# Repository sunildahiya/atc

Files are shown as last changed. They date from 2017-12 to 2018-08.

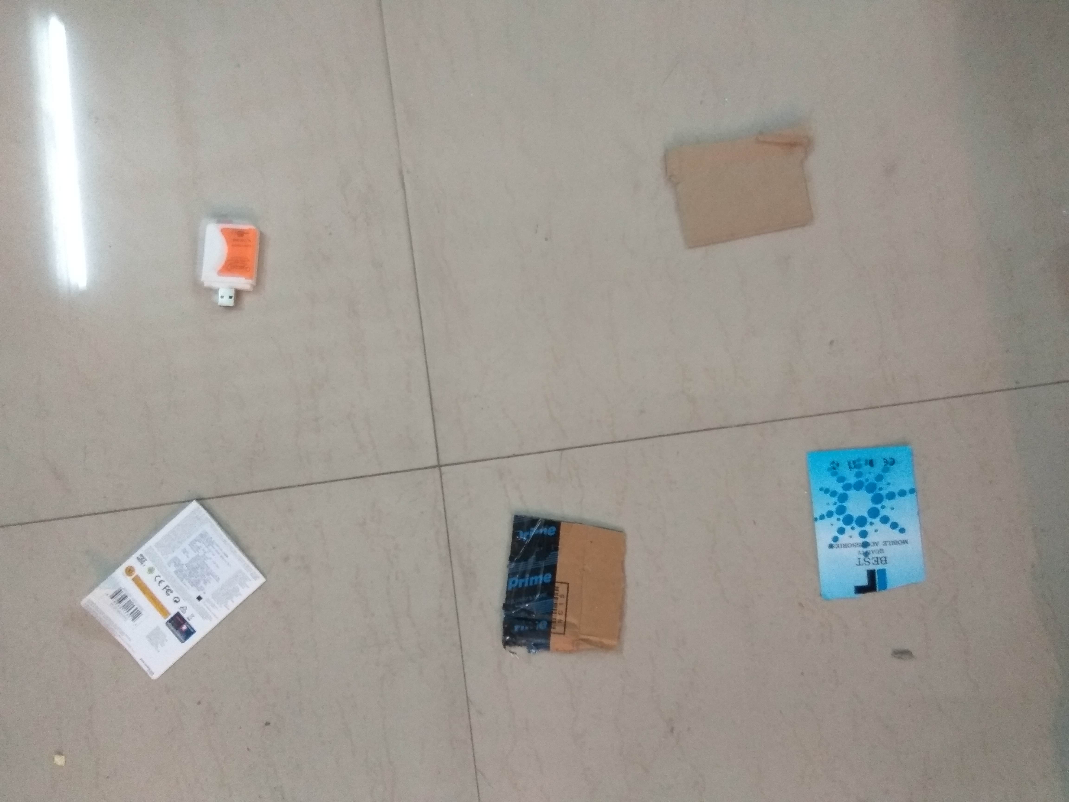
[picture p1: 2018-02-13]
ip/Resources/stain1.jpg

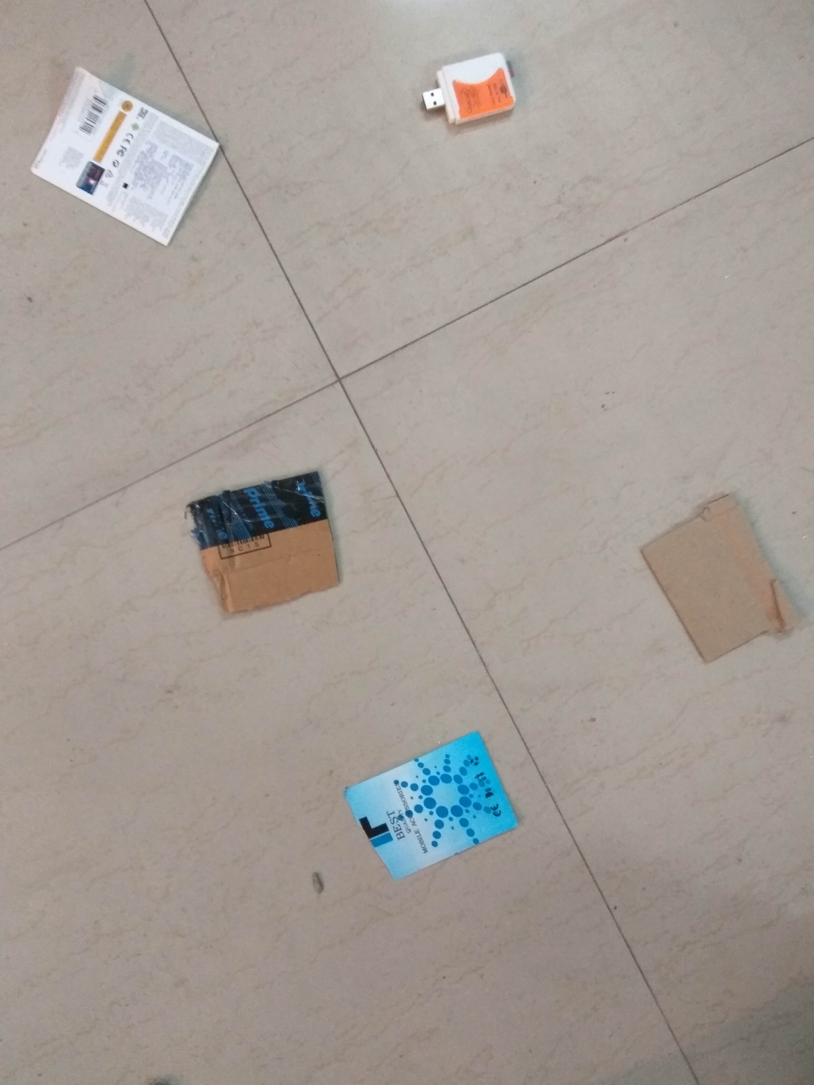
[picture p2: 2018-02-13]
ip/Resources/stain2.jpg

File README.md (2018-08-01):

### Automatic Toilet Cleaner
This repository contains Solidwork design, Navigation Code and IP code for InterIIT Automatic Toilet Cleaner Competition.

#### Minimal HSV Channels for detecting different Color

 1. White    -   Saturation from 0 to someValue
 2. Green    -   Using 1, hue 0 to someValue
 3. Blue     -   saturation from somevalue to 255
 4. Red      -   Using 3, hue from somevalue to 255

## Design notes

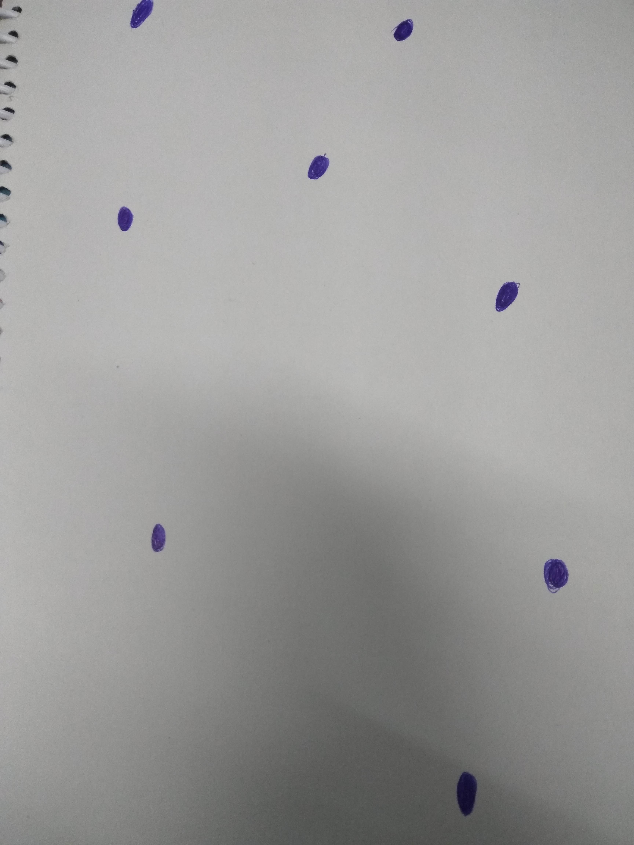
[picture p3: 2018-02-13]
ip/Resources/stains.jpg

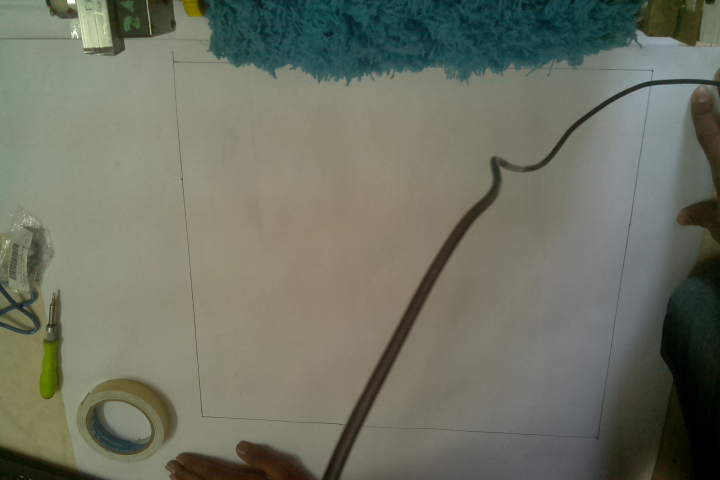
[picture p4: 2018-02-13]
ip/Resources/C.png

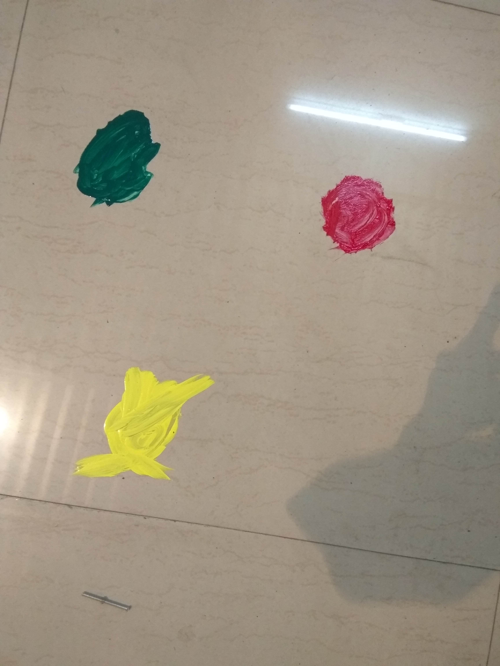
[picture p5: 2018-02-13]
ip/Resources/stain3.jpg

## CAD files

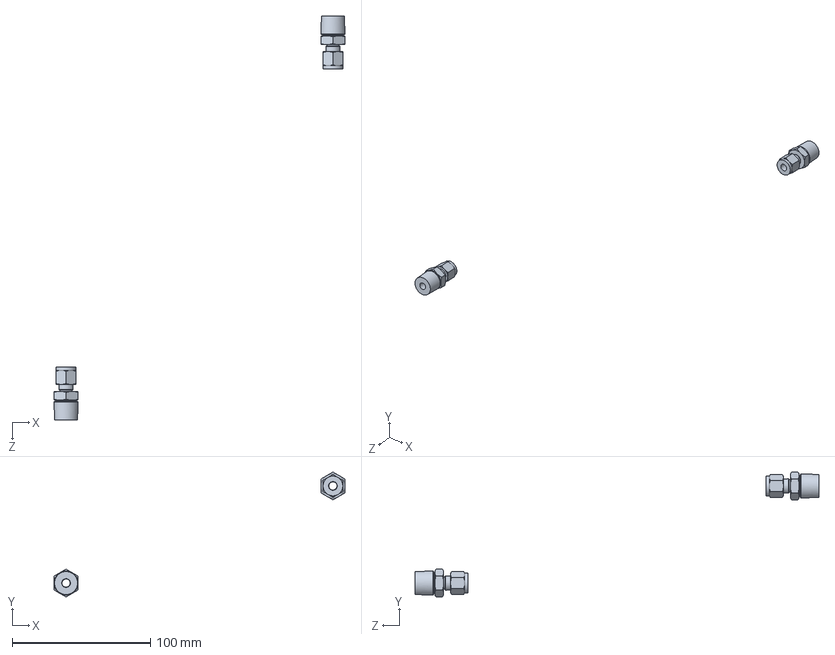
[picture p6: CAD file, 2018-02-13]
Solidworks_Design/Tube_8-Final_bot.sldasm
210.8 x 90.5 x 292.3 mm
straight fitting x 2

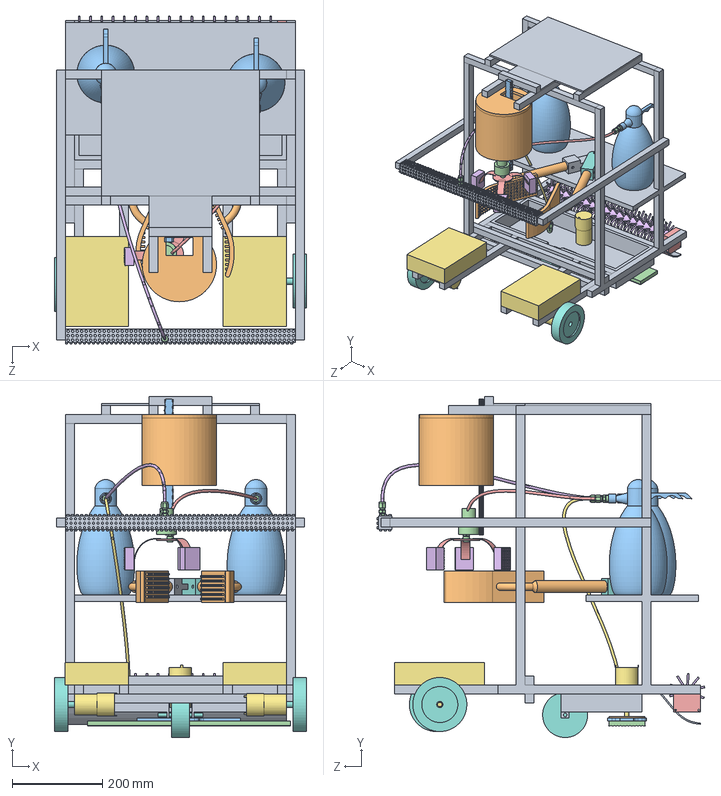
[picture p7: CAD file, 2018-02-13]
Solidworks_Design/Final_bot.SLDASM
560.0 x 756.7 x 727.2 mm
Chasis
cylindrcal shell
rack
motor_bowl
foam brush bowl x 3
motor x 3
wheel x 2
lower sheet trash
rotating circle
scotch piston
cleaning pad
roller motor
rolling brush
weight x 2
side clean brush x 2
wATER BOOTTLE x 2
straight fitting x 6
Tube-250X010^Tube_10-Final_bot
Tube-250X010^Tube_11-Final_bot
Tube-250X010^Tube_12-Final_bot
OMNI

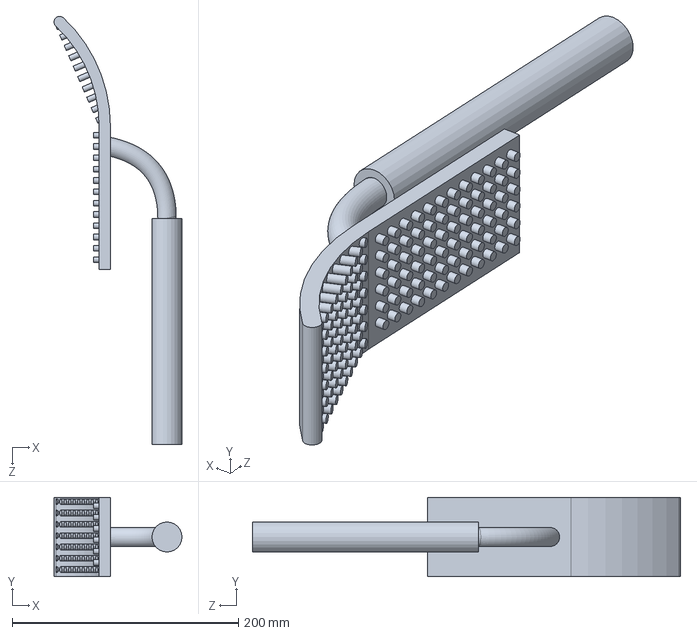
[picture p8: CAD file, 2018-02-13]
Solidworks_Design/side clean brush.SLDPRT
113.1 x 70.0 x 378.4 mm

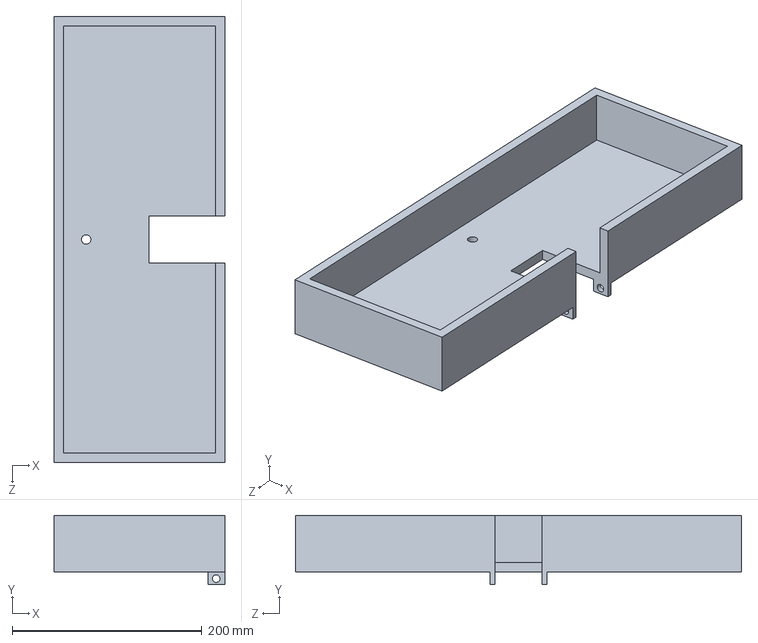
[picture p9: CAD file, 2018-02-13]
Solidworks_Design/lower sheet trash.SLDPRT
180.0 x 73.2 x 470.0 mm

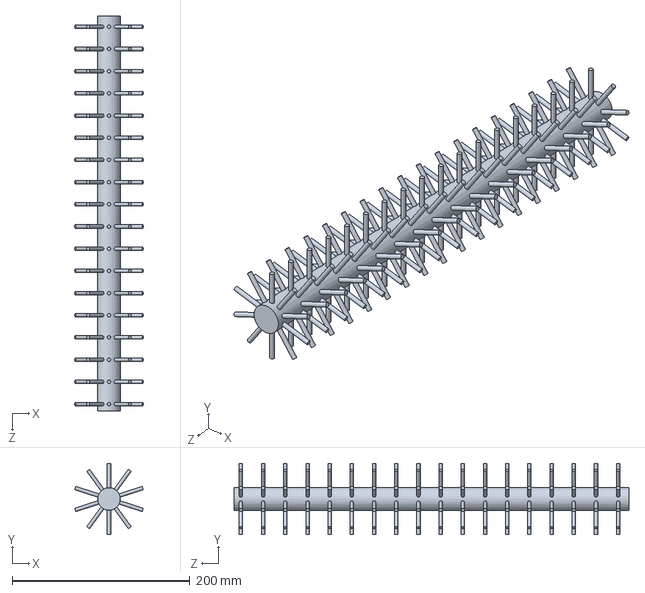
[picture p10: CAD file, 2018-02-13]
Solidworks_Design/rolling brush.SLDPRT
77.3 x 80.0 x 445.0 mm

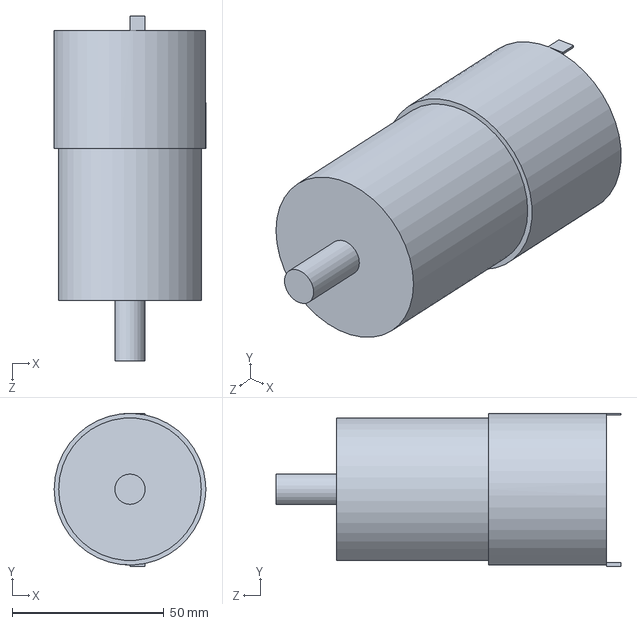
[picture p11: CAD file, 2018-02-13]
Solidworks_Design/motor.SLDPRT
50.0 x 50.5 x 113.7 mm

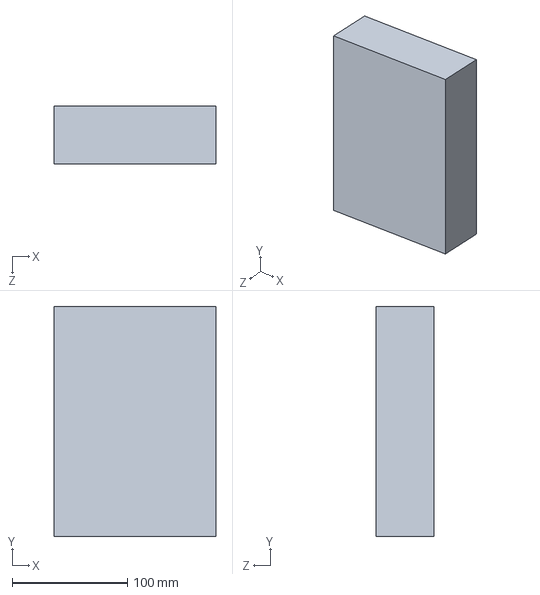
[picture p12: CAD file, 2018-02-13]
Solidworks_Design/weight.SLDPRT
140.8 x 200.0 x 50.0 mm

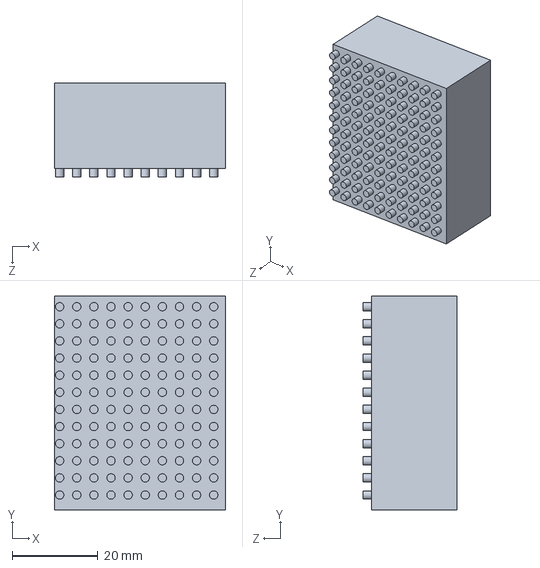
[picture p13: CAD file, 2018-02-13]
Solidworks_Design/foam brush bowl.SLDPRT
40.0 x 50.0 x 22.0 mm

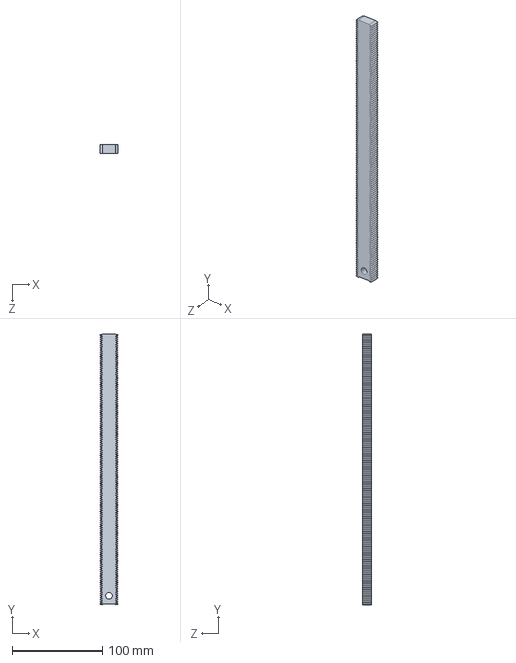
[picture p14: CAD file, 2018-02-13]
Solidworks_Design/rack.SLDPRT
20.0 x 301.1 x 10.0 mm

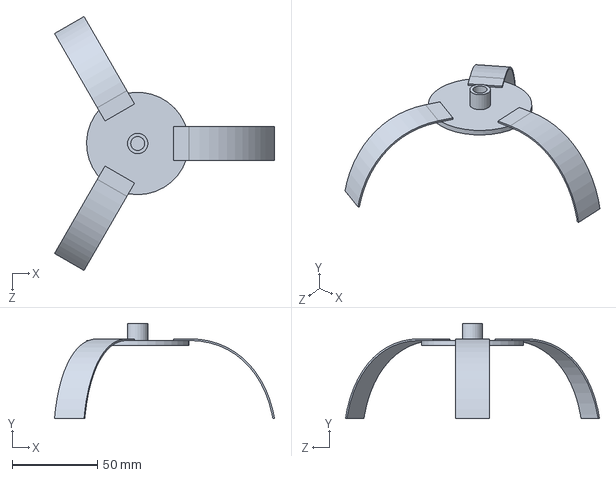
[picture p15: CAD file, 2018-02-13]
Solidworks_Design/Part4.SLDPRT
129.0 x 55.8 x 148.9 mm

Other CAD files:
Solidworks_Design/Tube_7-Final_bot.sldasm
Solidworks_Design/Tube_10-Final_bot.sldasm
Solidworks_Design/RouteAssy_1-Final_bot.sldasm
Solidworks_Design/Tube_11-Final_bot.sldasm
Solidworks_Design/Tube_6-Final_bot.sldasm
Solidworks_Design/Tube_9-Final_bot.sldasm
Solidworks_Design/Tube_12-Final_bot.sldasm
Solidworks_Design/Tube_2-Final_bot.sldasm
Solidworks_Design/Chasis.SLDPRT
Solidworks_Design/OMNI.SLDPRT
Solidworks_Design/cylindrcal shell.SLDPRT
Solidworks_Design/motor_bowl.SLDPRT
Solidworks_Design/roller motor.SLDPRT
Solidworks_Design/wheel.SLDPRT

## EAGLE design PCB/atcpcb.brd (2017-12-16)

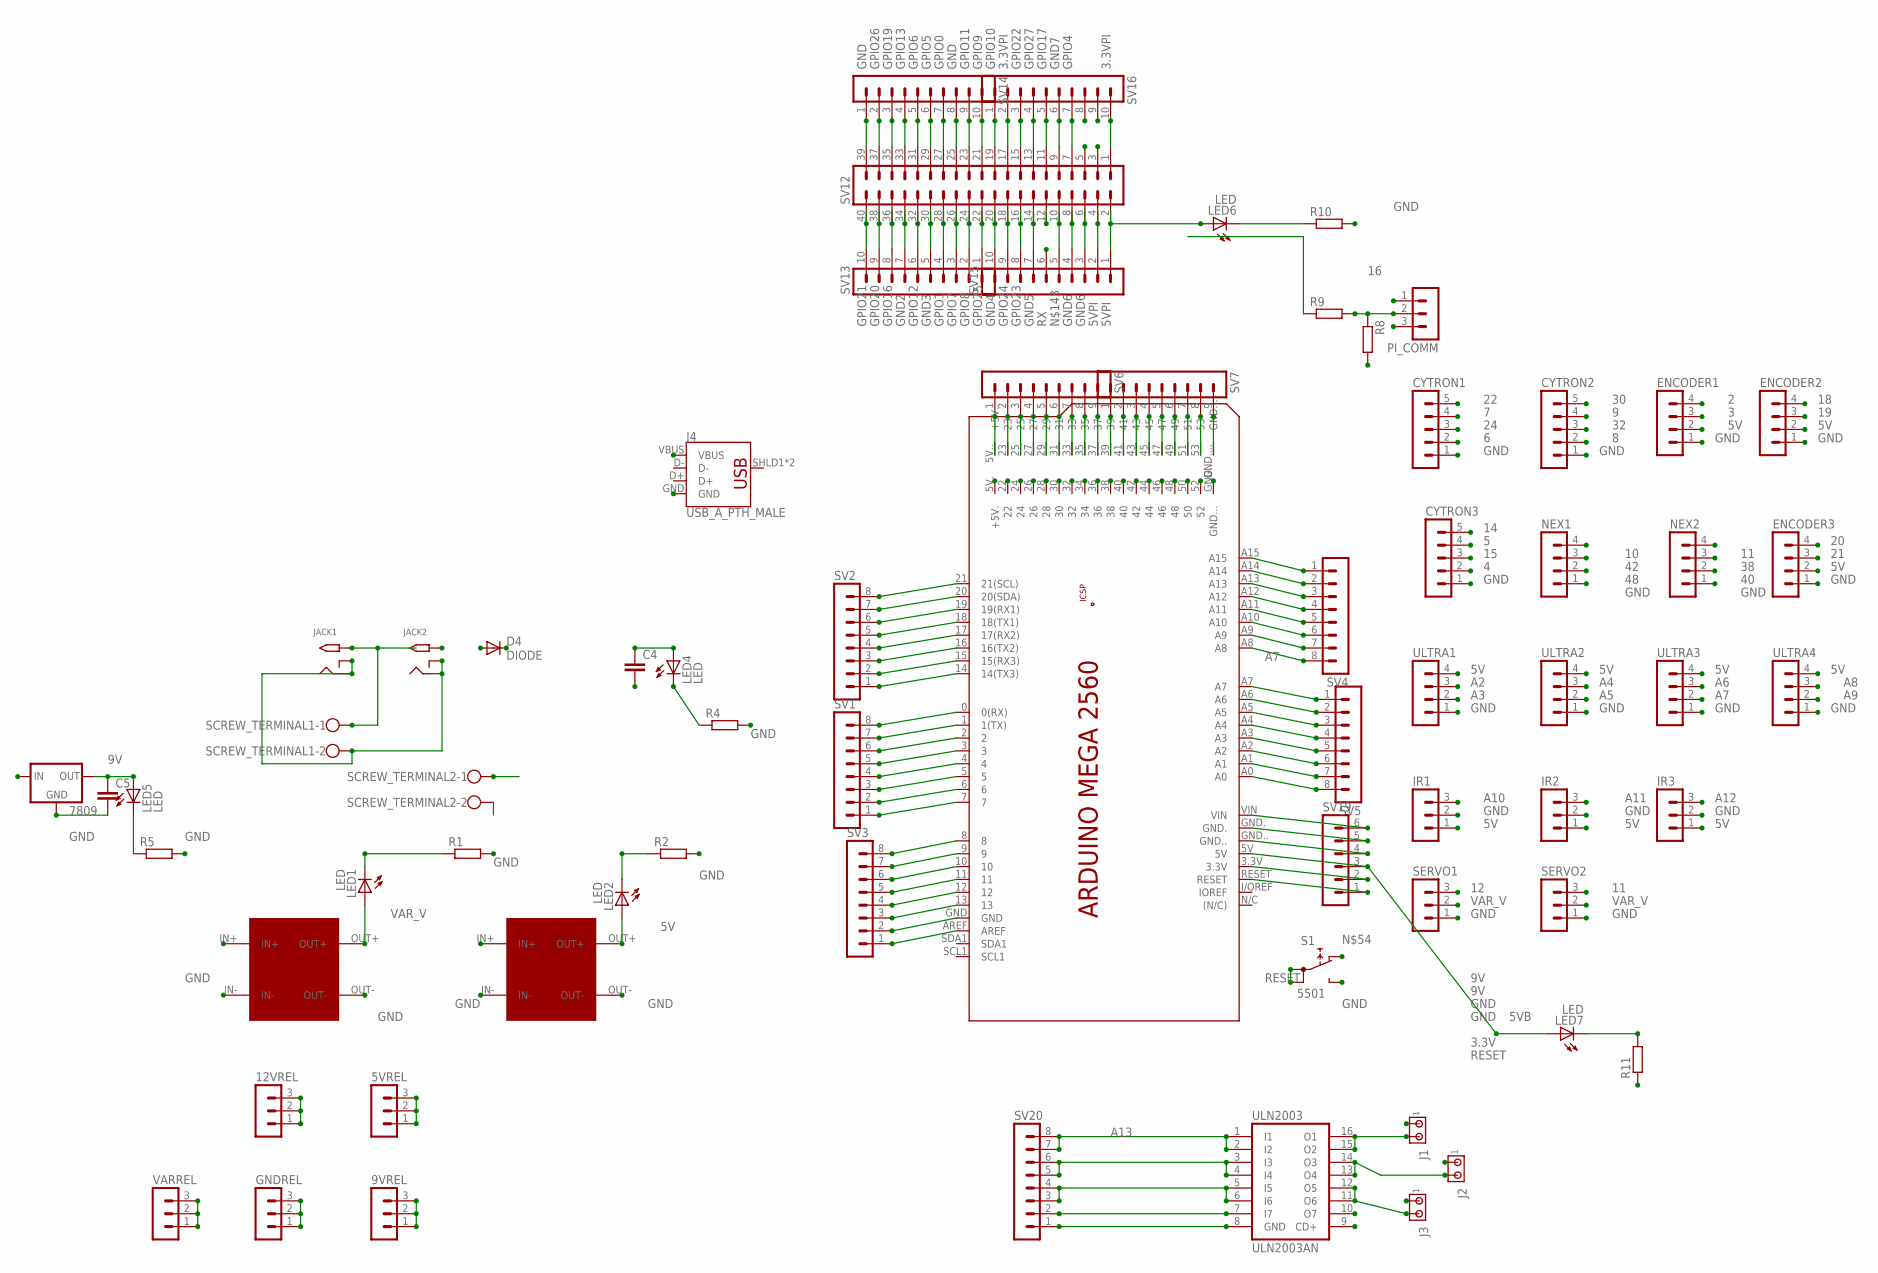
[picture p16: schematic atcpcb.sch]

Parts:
5VREL, 9VREL, 12VREL: RELIMATE_03-1; MA03-1
7809: VOLTAGE_REGULATOR_78XXS; 78XXS
C4, C5: CAPACITOR075-063X106; C075-063X106
CYTRON1, CYTRON2, CYTRON3: RELIMATE_05-1; MA05-1
D4: DIODE
ENCODER1, ENCODER2, ENCODER3: RELIMATE_04-1; MA04-1
GNDREL: RELIMATE_03-1; MA03-1
IR1, IR2, IR3: RELIMATE_03-1; MA03-1
J1, J2, J3: MTA02-100; 10X02MTA
J4: USB_A_PTH_MALE; USB-A-H
JACK1, JACK2: 2.1MM_POWER_JACKTHM; POWER_JACK
LED1, LED2, LED4, LED5, LED6, LED7: LED; LED3MM
NEX1, NEX2: RELIMATE_04-1; MA04-1
PCB1: ARDUINO_MEGA2560
PI_COMM: RELIMATE_03-1; MA03-1
R1, R2, R4, R5, R8, R9, R10, R11: RESISTANCE0207/10; 0207/10
S1: 5501
SCREW_TERMINAL1, SCREW_TERMINAL2: SCREW_TERMINAL_POWER; POWER_CONNECTOR
SERVO1, SERVO2: RELIMATE_03-1; MA03-1
SV1, SV2, SV3, SV4, SV5, SV20: RELIMATE_08-1; MA08-1
SV6, SV7: RELIMATE_09-1; MA09-1
SV12: RELIMATE_20-2; MA20-2
SV13, SV14, SV15, SV16: RELIMATE_10-1; MA10-1
SV19: RELIMATE_06-1; MA06-1
U$1, U$2: BUCK_CONVERTER; MPN LNK304DN
ULN2003: ULN2003AN; DIL16
ULTRA1, ULTRA2, ULTRA3, ULTRA4: RELIMATE_04-1; MA04-1
VARREL: RELIMATE_03-1; MA03-1

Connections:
0: PCB1.0 (0(RX)), SV1.8
1: PCB1.1 (1(TX)), SV1.7
2: ENCODER1.4, PCB1.2, SV1.6
3: ENCODER1.3, PCB1.3, SV1.5
3.3V: PCB1.3.3V, SV19.2
3.3VPI: SV12.1, SV12.17, SV16.2, SV16.10
4: CYTRON3.2, PCB1.4, SV1.4
5: CYTRON3.4, PCB1.5, SV1.3
5V: 5VREL.1, 5VREL.2, 5VREL.3, ENCODER1.2, ENCODER2.2, ENCODER3.2, IR1.1, IR2.1, IR3.1, J4.VBUS, LED2.A, U$2.OUT+, ULTRA1.4, ULTRA2.4, ULTRA3.4, ULTRA4.4
5VB: LED7.A, PCB1.5V, SV19.3
5VC: PCB1.5V. (+5V.), PCB1.5V.. (+5V..), SV6.1
5VPI: LED6.A, SV12.2, SV12.4, SV15.1, SV15.2
6: CYTRON1.2, PCB1.6, SV1.2
7: CYTRON1.4, PCB1.7, SV1.1
8: CYTRON2.2, PCB1.8, SV3.8
9: CYTRON2.4, PCB1.9, SV3.7
9V: 9VREL.1, 9VREL.2, 9VREL.3, 7809.OUT, C5.1, LED5.A, PCB1.VIN, SV19.6
10: NEX1.4, PCB1.10, SV3.6
11: NEX2.4, PCB1.11, SERVO2.3, SV3.5
12: PCB1.12, SERVO1.3, SV3.4
12V: 12VREL.1, 12VREL.2, 12VREL.3, 7809.IN, C4.1, D4.C, J1.1, J2.1, J3.1, LED4.A, U$1.IN+, U$2.IN+, ULN2003.9 (CD+)
13: PCB1.13, SV3.3
14: CYTRON3.5, PCB1.14 (14(TX3)), SV2.1
15: CYTRON3.3, PCB1.15 (15(RX3)), SV2.2
16: PCB1.16 (16(TX2)), PI_COMM.1, SV2.3
17: PCB1.17 (17(RX2)), PI_COMM.2, R8.1, R9.2, SV2.4
18: ENCODER2.4, PCB1.18 (18(TX1)), SV2.5
19: ENCODER2.3, PCB1.19 (19(RX1)), SV2.6
20: ENCODER3.4, PCB1.20 (20(SDA)), SV2.7
21: ENCODER3.3, PCB1.21 (21(SCL)), SV2.8
22: CYTRON1.5, PCB1.22
23: PCB1.23, SV6.2
24: CYTRON1.3, PCB1.24
25: PCB1.25, SV6.3
26: PCB1.26
27: PCB1.27, SV6.4
28: PCB1.28
29: PCB1.29, SV6.5
30: CYTRON2.5, PCB1.30
31: PCB1.31, SV6.6
32: CYTRON2.3, PCB1.32
33: PCB1.33, SV6.7
34: PCB1.34
35: PCB1.35, SV6.8
36: PCB1.36
37: PCB1.37, SV6.9
38: NEX2.3, PCB1.38
39: PCB1.39, SV7.1
40: NEX2.2, PCB1.40
41: PCB1.41, SV7.2
42: NEX1.3, PCB1.42
43: PCB1.43, SV7.3
44: PCB1.44
45: PCB1.45, SV7.4
46: PCB1.46
47: PCB1.47, SV7.5
48: NEX1.2, PCB1.48
49: PCB1.49, SV7.6
50: PCB1.50
51: PCB1.51, SV7.7
52: PCB1.52
53: PCB1.53, SV7.8
A0: PCB1.A0, SV5.8
A1: PCB1.A1, SV5.7
A2: PCB1.A2, SV5.6, ULTRA1.3
A3: PCB1.A3, SV5.5, ULTRA1.2
A4: PCB1.A4, SV5.4, ULTRA2.3
A5: PCB1.A5, SV5.3, ULTRA2.2
A6: PCB1.A6, SV5.2, ULTRA3.3
A7: PCB1.A7, SV5.1, ULTRA3.2
A8: PCB1.A8, SV4.8, ULTRA4.3
A9: PCB1.A9, SV4.7, ULTRA4.2
A10: IR1.3, PCB1.A10, SV4.6
A11: IR2.3, PCB1.A11, SV4.5
A12: IR3.3, PCB1.A12, SV4.4
A13: PCB1.A13, SV4.3, SV20.7, SV20.8, ULN2003.1 (I1), ULN2003.2 (I2)
A14: PCB1.A14, SV4.2, SV20.5, SV20.6, ULN2003.3 (I3), ULN2003.4 (I4)
A15: PCB1.A15, SV4.1, SV20.3, SV20.4, ULN2003.5 (I5), ULN2003.6 (I6)
AREF: PCB1.AREF, SV3.1
GND: 7809.GND, C4.2, C5.2, CYTRON1.1, CYTRON2.1, CYTRON3.1, ENCODER1.1, ENCODER2.1, ENCODER3.1, GNDREL.1, GNDREL.2, GNDREL.3, IR1.2, IR2.2, IR3.2, J4.GND, JACK1.RING, JACK1.RING_SW, JACK2.RING, JACK2.RING_SW, NEX1.1, NEX2.1, PCB1.GND, PCB1.GND., PCB1.GND.., PCB1.GND..., PCB1.GND...., PI_COMM.3, R1.2, R2.2, R4.2, R5.2, R8.2, R10.2, R11.1, S1.NO, SCREW_TERMINAL1.2, SCREW_TERMINAL2.2, SERVO1.1, SERVO2.1, SV3.2, SV7.9, SV12.25, SV12.39, SV14.1, SV14.8, SV19.4, SV19.5, SV20.1, U$1.IN-, U$1.OUT-, U$2.IN-, U$2.OUT-, ULN2003.8 (GND), ULTRA1.1, ULTRA2.1, ULTRA3.1, ULTRA4.1
GND2: SV12.34, SV13.7
GND3: SV12.30, SV13.5
GND4: SV12.20, SV15.10
GND5: SV12.14, SV15.7
GND6: SV12.6, SV12.8, SV15.3, SV15.4
GND7: SV12.9, SV16.6
GPIO0: SV12.27, SV14.7
GPIO1: SV12.28, SV13.4
GPIO4: SV12.7, SV16.7
GPIO5: SV12.29, SV14.6
GPIO6: SV12.31, SV14.5
GPIO7: SV12.26, SV13.3
GPIO8: SV12.24, SV13.2
GPIO9: SV12.21, SV14.10
GPIO10: SV12.19, SV16.1
GPIO11: SV12.23, SV14.9
GPIO12: SV12.32, SV13.6
GPIO13: SV12.33, SV14.4
GPIO16: SV12.36, SV13.8
GPIO17: SV12.11, SV16.5
GPIO19: SV12.35, SV14.3
GPIO20: SV12.38, SV13.9
GPIO21: SV12.40, SV13.10
GPIO22: SV12.15, SV16.3
GPIO23: SV12.16, SV15.8
GPIO24: SV12.18, SV15.9
GPIO25: SV12.22, SV13.1
GPIO26: SV12.37, SV14.2
GPIO27: SV12.13, SV16.4
unnamed: LED1.K (C), R1.1
unnamed: LED2.K (C), R2.1
unnamed: LED6.K (C), R10.1
unnamed: LED7.K (C), R11.2
unnamed: SV20.2, ULN2003.7 (I7)
unnamed: J1.2, ULN2003.15 (O2), ULN2003.16 (O1)
unnamed: J2.2, ULN2003.13 (O4), ULN2003.14 (O3)
unnamed: J3.2, ULN2003.11 (O6), ULN2003.12 (O5)
unnamed: LED4.K (C), R4.1
unnamed: LED5.K (C), R5.1
unnamed: SV12.10, SV15.5
RESET: PCB1.RESET, S1.1A, S1.1B, SV19.1
RX: R9.1, SV12.12, SV15.6
SCL: SV12.5, SV16.8
SDA: SV12.3, SV16.9
VAR_V: LED1.A, SERVO1.2, SERVO2.2, U$1.OUT+, VARREL.1, VARREL.2, VARREL.3
VIN: D4.A, JACK1.TIP, JACK2.TIP, SCREW_TERMINAL1.1, SCREW_TERMINAL2.1

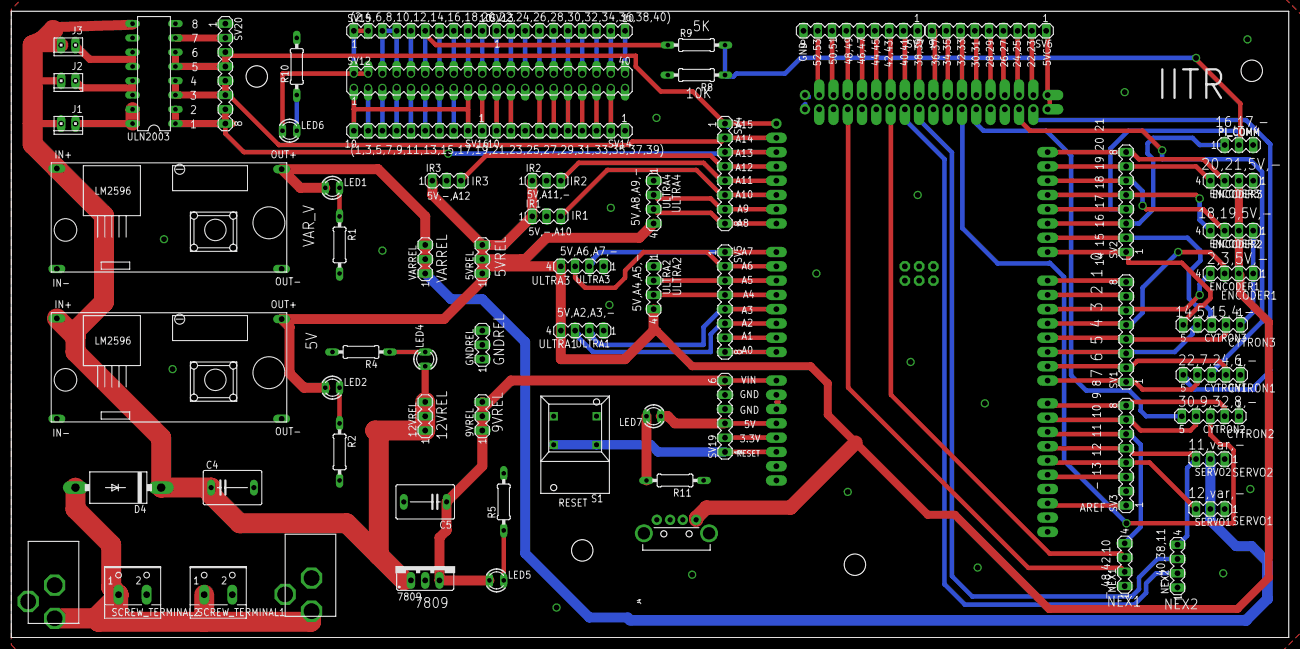
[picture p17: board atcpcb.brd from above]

Board: 2 copper layers, 227.3 x 111.4 mm, 68 parts (1 on the bottom side), 118 nets.

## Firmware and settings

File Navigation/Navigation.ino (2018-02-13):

#include <Servo.h>
#include <Driver.h>
#include <Fuzzy.h>
#include <Wire.h>
#include <MPU9250.h>

//Constants
#define wheelSeparation 39
#define wheelRadius 5
#define leftUltraDist 33  
#define frontUltraDist 25.5  
#define leftBackOmniDist 40
#define frontLeftOmniDist 18.5
#define forward 1
#define backward -1
#define front 1
#define left -1
#define up 1
#define down -1
#define c_clockwise 1
#define c_anticlockwise -1
#define rotDur 2400
#define entryDist 130 
#define marginDist 20
#define entranceLeftThresh 55
#define entranceFrontThresh 125 //To do
#define sc_clean1LeftSStopDist 60
#define sc_clean1FrontSBStopDist 50
#define sc_clean1LeftSBStopDist 100 
#define sc_clean1LeftSRotAngle 16
#define sc_clean1LeftSTiltDist 16

#define sc_clean1FStopDist 32
#define sc_clean2FStopDist 115
#define sc_clean2PStopDist 40
#define sc_clean3FStopDist 90
#define sc_clean3PStopDist 70
#define sc_cleanCFStopDist 110
#define sc_clean4BStopDist 70
#define sc_clean5BStopDist 70
#define sc_cleanRetFStopDist 30
#define sc_clean4RSlight 15
#define sc_clean5FStopDist 32


#define sc3_clean1FStopDist 35
#define sc3_clean2FLSStopDist 60
#define sc3_cleanRetFStopDist 110

#define s3_clean1F 301
#define s3_clean122 302
#define s3_clean2FLS 303
#define s3_clean2FFS 304
#define s3_clean223 305
#define s3_cleanRetF 306

#define s2_cleanlR 201

#define rackIRPin A0
#define commodeIRPin A1

#define s_entry 1
#define s_clean1LeftSAllign 2
#define s_clean1LeftS 3
#define s_clean1FrontS 4
#define s_clean1FrontSB 5
#define s_clean1LeftSB 6
#define s_clean1LeftSRotSlight 7
#define s_clean1FrontRightSShift 9 
#define s_clean1LeftSRot90 10
#define s_stop -1
#define s_clean1LeftSTilt 12


#define s_clean1LeftSAllign2 14
#define s_clean1F 15
#define s_clean122 16
#define s_clean2F 17
//#define s_clean2B 15
#define s_clean2R 18
#define s_clean2P 19
#define s_clean223 20
#define s_clean3F 21
#define s_clean3R 22
#define s_clean3P 23
#define s_clean32C 25
#define s_cleanCB 26

#define s_cleanCommode 27

#define s_cleanCF 28
#define s_cleanC23 29
#define s_clean3P2 30
#define s_clean324 31
#define s_clean4F 32
#define s_clean4RSlight 42
#define s_clean4B 33

#define s_clean425 34

#define s_clean5F 35
#define s_clean5R 36
#define s_clean5P 37
#define s_clean5B 38
#define s_cleanRetR 39
#define s_cleanRetF 40
#define s_cleanRetFinish 41
 
int state = 1;
bool finishStarting = false;

double leftRefDist = 20;
double frontRefDist = 25;
double sv_clean1LeftStopF = 0, sv_clean1LeftStopI = 0, sv_clean1FrontStop = 0;

//Encoder Interrupt Pins
#define encoderPinRight1 18
#define encoderPinRight2 19
#define encoderPinLeft1 20
#define encoderPinLeft2 21

//Motor Driver Pins
#define motorRightEnPin 11
#define motorRightDirPin 30
#define motorLeftEnPin 10
#define motorLeftDirPin 28

//Ultrasonic Sensors Left
#define leftFrontTrigPin A6 
#define leftFrontEchoPin A7  
#define leftBackTrigPin A3
#define leftBackEchoPin  A2 

//Ultrasonic Sensors Front
#define frontLeftTrigPin A8
#define frontLeftEchoPin A9  
#define frontRightTrigPin A5 
#define frontRightEchoPin A4 

//Commode Mechanism
#define commodeRackEnPin 44
#define commodeRackDirPin 34
#define commodeCleanEnPin 46
#define commodeCleanDirPin 32

//Floor Mechanism
#define rollerEnPin 4
#define rollerDirPin1 22
#define rollerDirPin2 23
#define mopEnPin 8
#define mopDirPin1 39
#define mopDirPin2 37

#define servoCommode 3
#define servoMop 2

Servo commodeServo;
 
//Motor Driver Objects
Driver motorRight(motorRightDirPin, motorRightEnPin);
Driver motorLeft(motorLeftDirPin, motorLeftEnPin);

Driver commodeRackMotor(commodeRackDirPin, commodeRackEnPin);
Driver commodeCleanMotor(commodeCleanDirPin, commodeCleanEnPin);

Driver rollerMotor(rollerDirPin1, rollerDirPin2, rollerEnPin);
Driver mopMotor(mopDirPin1, mopDirPin2, mopEnPin);

//Fuzzy
//Fuzzy fuzzy(12, 5, 40, 0); //error, derror, correction and centre

double kp = 10, kd = 1;
double error = 0, derror = 0, prevError = 0, correction = 0;
double xError = 0, angleError = 0;
int basePWM = 100;
int basePWMRotate_d = 120;
int basePWMRotate_imu = 120;
int basePWMRotate_s = 90;

//
//int basePWM = 100;
//int basePWMRotate_d = 10;
//int basePWMRotate_imu = 90;
//int basePWMRotate_s = 90;
double x = 0, y = 0, angle = 0;

long leftFrontDur = 0, leftBackDur = 0;
double leftFrontDist = 0, leftBackDist = 0;

double movingAvgLeftFront[10];
double movingAvgLeftBack[10];
double movingAvgLeftFrontV=0, movingAvgLeftBackV=0;


long frontLeftDur = 0, frontRightDur = 0;
long frontLeftDist = 0, frontRightDist = 0;

double movingAvgFrontLeft[10];
double movingAvgFrontRight[10];
double movingAvgFrontLeftV=0, movingAvgFrontRightV=0;

int16_t gyro[3] = {0, 0, 0};
MPU9250 jholImu;
double timer = 0;
double gyroZangle = 0;

long start_i;
int stage = s_clean1LeftSAllign;
//int stage = s_stop;
void calc_correction(int dir, int sensor, int shiftRef, double angleRef = 0);
void allign(int sensor, double angleRef = 0.0);

int entranceNo = 1;

int initial_angle = 0;
int final_angle = 0;

void setup() {
  Serial.begin (9600);
 
  pinMode(leftFrontTrigPin, OUTPUT); 
  pinMode(leftFrontEchoPin, INPUT); 
  pinMode(leftBackTrigPin, OUTPUT); 
  pinMode(leftBackEchoPin, INPUT);
  pinMode(frontLeftTrigPin, OUTPUT); 
  pinMode(frontLeftEchoPin, INPUT); 
  pinMode(frontRightTrigPin, OUTPUT); 
  pinMode(frontRightEchoPin, INPUT);
  
  pinMode(commodeIRPin, INPUT);
  pinMode(rackIRPin, INPUT);
//  test_ultra();
  jholImu.initMPU9250();
  timer = micros();
  gyroZangle = 0;
  commodeServo.attach(servoCommode);
  commodeServo.write(initial_angle);
//  test_imu();
  Serial.println("Before");
  init_ultra();
  
//  if (leftBackDist < entranceLeftThresh && frontRightDist > entranceFrontThresh)
    entranceNo = 1;
//  else if(leftBackDist > entranceLeftThresh){
//    entranceNo = 3;
//    stage = s3_clean1F;
//  }
  
  Serial.println("Starting......");
  serial_tab(entranceNo);
  Serial.println(stage);
  Serial.println("Loop Start");
  rollerMotor.clockwise(55);
//  reset_rack();
}


void loop(){
  
  if (state == 1 && entranceNo == 1)
    clean_state1_ent1();
    
  else if (state == 1 && entranceNo == 2 && !finishStarting)
    clean_state1_ent2();
    
  else if (state == 1 && entranceNo == 2 && finishStarting)
    clean_state1_ent1();

  else if(state == 1 && entranceNo == 3 && !finishStarting)
    clean_state1_ent3();

  else if(state == 1 && entranceNo == 3 && finishStarting)
    clean_state1_ent1();
   
  else if (state == 2)
    clean_state2();
    
  else if(state == 3 && (entranceNo == 1 || entranceNo == 2))
    clean_state3_ent12();
    
  else if(state == 3 && entranceNo == 3)
    clean_state3_ent3();
    
  else if(state == 4)
    clean_state4();
  
 
//  read_ultra();
//  find_moving_avg();
//  serial_print();

}

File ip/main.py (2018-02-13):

# from picamera.array import PiRGBArray
# from picamera import PiCamera
import cv2
import time
import numpy as np

from matplotlib import pyplot as plt
from matplotlib import cm
from mpl_toolkits.mplot3d import Axes3D
import matplotlib.patches as patches
import matplotlib.path as path

from staindet import *
from Point import *
from util_func import *
from Blob import *
from merge_blobs import *

STAINS_IMG_KERNEL = [200, 200]
STAINS_HIST_KERNEL = 20
STAINS_MEDIANBLUR_THRESH = 21
STAINS_CONTOURAREA_THRESH = 4000
STAINS_MERGE_MAXDIST = 500

SERIAL_START_CHAR = "\n"
SERIAL_END_CHAR = "\n"

# initialize the camera and grab a reference to the raw camera capture
# camera = PiCamera()
# rawCapture = PiRGBArray(camera)
 
# # allow the camera to warmup
# time.sleep(0.1)
 
# grab an image from the camera
# camera.capture(rawCapture, format="bgr")
# img = rawCapture.array
img = cv2.imread('Resources/stain1.jpg')
img_gray = cv2.cvtColor(img, cv2.COLOR_BGR2GRAY)
img_gray = cv2.GaussianBlur(img_gray, (9, 9), 0)

img_bw = get_stains_pos(img_gray, STAINS_IMG_KERNEL, STAINS_HIST_KERNEL)
img_bw = cv2.medianBlur(img_bw, STAINS_MEDIANBLUR_THRESH)

blobs  = getBlobProps(img_bw)

mainBlobs = []
splitBlobs = []


for i in range(0, len(blobs.centroids)):
    cv2.circle(img_gray, blobs.centroids[i].as_tuple(), 63, (255, 0, 0), -1)

for i in range(0, len(blobs.contourareas)):
    if (blobs.contourareas[i] > STAINS_CONTOURAREA_THRESH):
        mainBlobs.append( [blobs.centroids[i], blobs.contourareas[i]] )        
    else:
        splitBlobs.append( [blobs.centroids[i], blobs.contourareas[i]] )

finalBlobs = merge_blobs(mainBlobs, splitBlobs, STAINS_MERGE_MAXDIST)
# for i in range(0, len(finalBlobs)):
#     print(finalBlobs[i])
for i in range(0, len(finalBlobs)):
    cv2.circle(img, finalBlobs[i][0].as_tuple(), 63, (255, 0, 0), -1)

print(len(finalBlobs))
cv2.namedWindow("Blob", cv2.WINDOW_NORMAL)
cv2.imshow("Blob", img)
cv2.namedWindow("Blob Prev", cv2.WINDOW_NORMAL)
cv2.imshow("Blob Prev", img_gray)
cv2.namedWindow("Blob BW", cv2.WINDOW_NORMAL)
cv2.imshow("Blob BW", img_bw)

cv2.waitKey(0)
# for i in range(0, len(finalBlobs)):

# display the image on screen and wait for a keypress
# cv2.imshow("Image", image)
# cv2.waitKey(0)

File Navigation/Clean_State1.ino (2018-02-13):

void clean_state1_ent1(){
    Serial.println("Entry");
    if(stage == s_clean1LeftSAllign){
      serial_twoln("Chutiya:\t", stage);
      allign(left, 0.0);
      delay(100);
      read_ultra();
      find_moving_avg();
      leftRefDist = movingAvgLeftBackV;
      stage = s_clean1LeftS;
    }
    else if(stage == s_clean1LeftS){
      serial_twoln("Chutiya:\t", stage);
      if (frontRightDist > sc_clean1LeftSStopDist){
        read_ultra();
        find_moving_avg();
        calc_correction(forward, left, leftRefDist);
        apply_correction(forward);
      }
      else
        stage = s_clean1FrontS;
    }
    else if(stage == s_clean1FrontS){
      serial_twoln("Chutiya:\t", stage);
      if (frontRightDist > marginDist){
        read_ultra();
        find_moving_avg();
        calc_correction(forward, front, -1);
        apply_correction(forward);
        serial_print();
      }
      else{
        apply_correction(0);
        stage = s_clean1FrontSB;
        delay(1000);
        recalibrate();
      }
    }
    else if(stage == s_clean1FrontSB){
      serial_twoln("Chutiya:\t", stage);
      if (frontRightDist < sc_clean1FrontSBStopDist){
        read_ultra();
        find_moving_avg();
        calc_correction(backward, front, -1);
        apply_correction(backward);
      }
      else{
        stage = s_clean1LeftSB;
        recalibrate();
      }
    }
    else if(stage == s_clean1LeftSB){
      serial_twoln("Chutiya:\t", stage);
      if (frontLeftDist < sc_clean1LeftSBStopDist){
        read_ultra();
        find_moving_avg();
        calc_correction(backward, left, leftRefDist);
        apply_correction(backward);
      }
      else{
        apply_correction(0);
        delay(500);
        allign(left, 0);
        delay(1000);
        sv_clean1FrontStop = frontRightDist-87.63+frontLeftOmniDist;
        stage = s_clean1LeftSRotSlight;
      }
    }
    else if(stage == s_clean1LeftSRotSlight){
      serial_twoln("Chutiya:\t", stage);
      allign(left, sc_clean1LeftSRotAngle);
//      rotate_imu(c_clockwise, sc_clean1LeftSRotAngle);
      stage = s_clean1LeftSTilt;
      delay(1000);
      calc_correction(forward, left, -1);
      sv_clean1LeftStopF = leftBackOmniDist*(1-tan(angleError*3.14/180))+sv_clean1FrontStop*tan(angleError*3.14/180)/cos(angleError*3.14/180)+leftBackDist-29;

    }
    else if(stage == s_clean1LeftSTilt){
      serial_twoln("Chutiya:\t", stage);
      if (leftBackDist < sv_clean1LeftStopF){
        read_ultra();
        find_moving_avg();
        correction = 0;
        apply_correction(forward);
      }
      else{
        apply_correction(0);
        stage = s_clean1LeftSAllign2;
        delay(1000);  
      }
    }

    else if(stage == s_clean1LeftSAllign2){
      serial_twoln("Chutiya:\t", stage);
      read_ultra();
      find_moving_avg();
      rotate_imu(c_anticlockwise, angleError);
      allign(left, 0.0);
      recalibrate();
      stage = s_clean1F;
    }

    else if(stage == s_clean1F){
      serial_twoln("Chutiya:\t", stage);
      if (frontRightDist > sc_clean1FStopDist){
        read_ultra();
        find_moving_avg();
        calc_correction(forward, front, -1);
        apply_correction(forward);
      }
      else{
        stage = s_clean122;
        apply_correction(0);
        delay(1000);
      }
    }

    else if(stage == s_clean122){
      serial_twoln("Chutiya:\t", stage);
      serial_print();
      rotate_imu(c_clockwise, 90);
      delay(600);
      recalibrate();
      allign(left, 0);
      long initial_ = millis();
      long timePassed = 0;
      while (timePassed < 600){
        correction = 0;
        apply_correction(forward);
        timePassed = millis()-initial_;
      }
      stage = s_clean2F;
      state = 2;
    }
}


void clean_state1_ent2(){
    state = 2;
    stage = s_clean2F;
    finishStarting = true;
}

void clean_state1_ent3(){
  Serial.println(stage);
  if (stage == s3_clean1F){
      if (frontRightDist > sc3_clean1FStopDist){
        read_ultra();
        find_moving_avg();
        calc_correction(forward, front, -1);
        apply_correction(forward);
      }
      else{
        apply_correction(0);
        delay(500);
        stage = s3_clean122;
      }
  }
  else if(stage == s3_clean122){
    rotate_imu(c_clockwise, 90);
    delay(500);
    stage = s3_clean2FLS;
    recalibrate();
    leftRefDist = movingAvgLeftBackV;
  }
  else if(stage == s3_clean2FLS){
    if (frontRightDist > sc3_clean2FLSStopDist){
      read_ultra();
      find_moving_avg();
      calc_correction(forward, left, leftRefDist);
      apply_correction(forward);
    }
    else
      stage = s3_clean2FFS;
  }
  else if(stage == s3_clean2FFS){
    if (frontRightDist > marginDist+15){
      read_ultra();
      find_moving_avg();
      calc_correction(forward, front, -1);
      apply_correction(forward);
    }
    else{
      apply_correction(0);
      delay(500);
      stage = s3_clean223;
    }
  }
  else if(stage == s3_clean223){
    rotate_imu(c_clockwise, 90);
    delay(500);
    stage = s_clean1LeftSAllign;
    state = 1;
    finishStarting = true;
    Serial.println("Exit");
  }
}

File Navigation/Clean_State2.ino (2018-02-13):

void clean_state2(){
  if(stage == s_clean2F){
    serial_twoln("Chutiya:\t", stage);
    if (frontLeftDist > sc_clean2FStopDist){
      read_ultra();
      find_moving_avg();
      correction = 0;
      apply_correction(forward);  
    }
    else{
      apply_correction(0);
      stage = s_clean2R;
      delay(1000);
    }
  }

  else if(stage == s_clean2R){
    serial_twoln("Chutiya:\t", stage);
    rotate_imu(c_clockwise, 90);
    delay(200);
    recalibrate();
//    allign(front, 0);
    delay(500);
    recalibrate();
    stage = s_clean2P;
  }

  else if(stage == s_clean2P){
    serial_twoln("Chutiya:\t", stage);
    if (frontLeftDist > sc_clean2PStopDist){
      read_ultra();
      find_moving_avg();
//      calc_correction(forward, front, -1);
      correction = 0;
      apply_correction(forward); 
    }
    else{
      apply_correction(0);
      stage = s_clean223; 
      delay(1000);
    }
  }

  else if(stage == s_clean223){
    serial_twoln("Chutiya:\t", stage);
    recalibrate();
    calc_correction(forward, left, -1);
    rotate_imu(c_anticlockwise, 90);
    delay(300);
    recalibrate();
//    allign(front, 0);
    delay(200);
    recalibrate();
    stage = s_clean3F;
  }

  else if(stage == s_clean3F){
    serial_twoln("Chutiya:\t", stage);
    if (frontLeftDist > sc_clean3FStopDist){
      read_ultra();
      find_moving_avg();
      correction = 0;
      apply_correction(forward);
    }
    else{
      stage = s_clean3R;
      apply_correction(0);
    }
  }

  else if(stage == s_clean3R){
    serial_twoln("Chutiya:\t", stage);
//    recalibrate();
//    calc_correction(forward, front, -1);
    rotate_imu(c_anticlockwise, 90);
    delay(200);
    recalibrate();    
    stage = s_clean3P;
  }

  else if(stage == s_clean3P){
    serial_twoln("Chutiya:\t", stage);
    if (frontRightDist > sc_clean3PStopDist){
      read_ultra();
      find_moving_avg();
      correction = 0;
      apply_correction(forward);
    }
    else{
      apply_correction(0);
      stage = s_clean32C;
      delay(1000);
    } 
  }

  else if(stage == s_clean32C){
    serial_twoln("Chutiya:\t", stage);
    recalibrate();
    rotate_imu(c_anticlockwise, 90);
    delay(500);
    allign(left, 0);
    delay(500);
    stage = s_cleanCB;
    recalibrate();
    
  }

  else if(stage == s_cleanCB){
    serial_twoln("Chutiya:\t", stage);
    correction = 0;
    while(digitalRead(commodeIRPin) == 1)
      apply_correction(backward);
    apply_correction(0);
    delay(1000);
    stage = s_cleanCommode;
    recalibrate();
  }
  else if(stage == s_cleanCommode){
    Serial.println("Start");
    commodeServo.write(final_angle);
    for (int i=0; i<3; i++){
      commodeCleanMotor.anticlockwise(130);
      move_rack(down, 200);
      move_rack(down);
      move_rack(up, 200);
      move_rack(up);
    }
    commodeServo.write(initial_angle);
    commodeCleanMotor.stall();
    stage = s_cleanCF;
    commodeServo.write(0); 
    Serial.println("Finish");
  }

  else if (stage == s_cleanCF){
    if (frontRightDist > sc_cleanCFStopDist){
      read_ultra();
      find_moving_avg();
      calc_correction(forward, left, leftRefDist);
      apply_correction(forward);
    }
    else{
      apply_correction(0);
      delay(1000);
      stage = s_cleanC23;
    }
  }

  if (stage == s_cleanC23){
    recalibrate();
    allign(front, 0);
    delay(1000);
    calc_correction(forward, front, -1);
    rotate_imu(c_clockwise, 90);
    delay(1000);
    stage = s_clean3P2;
    recalibrate();
  }

  if (stage == s_clean3P2){
    if (frontRightDist > marginDist){
      read_ultra();
      correction = 0;
      apply_correction(forward);
    }
    else{
      apply_correction(0);
      stage = s_clean324;
      delay(1000);
    }
  }

  if (stage == s_clean324){
    rotate_imu(c_clockwise, 90);
    delay(400);
    recalibrate();
    allign(front, 0);
    delay(1000);
    stage = s_clean4F;
    recalibrate();
  }

  else if (stage == s_clean4F){
    if (frontRightDist > marginDist){
      read_ultra();
      find_moving_avg();
      calc_correction(forward, front, -1);
      apply_correction(forward);
    }
    else{
      apply_correction(0);
      delay(1000);
      stage = s_clean4RSlight;
    }
  }

  else if(stage == s_clean4RSlight){
    rotate_imu(c_anticlockwise, sc_clean4RSlight);
    delay(1000);
    stage = s_clean4B;
  }

  else if(stage == s_clean4B){
    if (frontRightDist < sc_clean4BStopDist){
      read_ultra();
      correction = 0;
      apply_correction(backward);
    }
    else{
      apply_correction(0);
      stage = s_clean425;
      delay(1000);
    }
  }

  else if(stage == s_clean425){
    recalibrate();
    rotate_imu(c_clockwise, 90+sc_clean4RSlight);
    delay(1000);
    allign(front, 0);
    delay(1000);
    stage = s_clean5F;
    recalibrate();
  }

  else if(stage == s_clean5F){
    if (frontRightDist > sc_clean5FStopDist){
      read_ultra();
      find_moving_avg();
      calc_correction(forward, front, -1);
      apply_correction(forward);
    }
    else{
      apply_correction(0);
      stage = s_clean5R;
      delay(1000);
    }
  }

  else if(stage == s_clean5R){
    rotate_imu(c_anticlockwise, 90);
    delay(1000);
    recalibrate();
    allign(front, 0);
    delay(1000);
    stage = s_clean5P;
    recalibrate();
  }

  else if(stage == s_clean5P){
    if (frontRightDist > marginDist){
      read_ultra();
      find_moving_avg();
      calc_correction(forward, front, -1);
      apply_correction(forward);
    }
    else{
      apply_correction(0);
      delay(1000);
      stage = s_clean5B;
      recalibrate();
    }
  }

  else if(stage == s_clean5B){
    if (frontRightDist < sc_clean5BStopDist){
      read_ultra();
      find_moving_avg();
      calc_correction(backward, front, -1);
      apply_correction(backward);
    }
    else{
      apply_correction(0);
      stage = s_cleanRetR;
      delay(1000);
      state = 3;
    }
  }
}

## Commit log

2017-12-06 Code is added to calculate bot position using encoder
2017-12-16 Fixed issues and added code to navigate bot using encoders in straight line
    [Correction.ino, Navigation.ino]
2017-12-16 Added PCB eagle design
    [atcpcb.brd, atcpcb.sch]
2017-12-21 Fixed some syntax issues and tune pid parameter
    [Correction.ino, Navigation.ino]
2017-12-24 Added code to navigate bot in straight line using ultrasonic sensor
2017-12-25 Added code for reading front ultrasonic sensor and fixes issues
    [Correction.ino, Navigation.ino, Ultrasonic.ino]
2017-12-25 Fix backward direction correction issue and tune PID parameters
    [Correction.ino, Navigation.ino]
2017-12-26 Added code to navigate bot in straight line using front ultrasonic for angle and left ultrasonic for shift correction
    [Correction.ino, Navigation.ino, Ultrasonic.ino]
2017-12-26 Added code to rotate bot by 90 degree and allign itself to left sensors
2017-12-27 Added code to clean stage 1 but need some fixes
    [Correction.ino, Navigation.ino, Serial_Print.ino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]
2017-12-28 Added code for stage 2(commode) cleaning
2017-12-30 Code is added to read IMU
2017-12-30 Serial print util functions are added
2017-12-31 Code is added for stage 3 upto commode
2018-01-01 Navigation motor driver is changed
2018-01-02 Code is added to clean upto stage 4
2018-01-12 Added code for serial communication via arduino cable between arduino and raspberry pi
2018-02-13 Add final bot solidworks design
    [Chasis.SLDPRT, Final_bot.SLDASM, OMNI.SLDPRT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]

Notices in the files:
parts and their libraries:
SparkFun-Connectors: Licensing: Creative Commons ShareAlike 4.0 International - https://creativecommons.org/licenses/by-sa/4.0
